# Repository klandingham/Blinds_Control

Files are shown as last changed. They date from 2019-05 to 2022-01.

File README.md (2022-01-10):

# Automatic Blinds Control with NodeMCU

A project to automatically open/close venetian blinds.

## Overall Description

## Circuit Operation

These are the elements outlined in John Gruber’s original design document. All Markdown applications support these elements.

### Heading

# H1
## H2
### H3

### Bold

**bold text**

### Italic

*italicized text*

### Blockquote

> blockquote

### Ordered List

1. First item
2. Second item
3. Third item

### Unordered List

- First item
- Second item
- Third item

### Code

`code`

### Horizontal Rule

---

### Link

[Markdown Guide](https://www.markdownguide.org)

### Image



## Extended Syntax

These elements extend the basic syntax by adding additional features. Not all Markdown applications support these elements.

### Table

| Syntax | Description |
| --- | --- |
| Header | Title |
| Paragraph | Text |

### Fenced Code Block

```
{
  "firstName": "John",
  "lastName": "Smith",
  "age": 25
}
```

### Footnote

Here's a sentence with a footnote. [^1]

[^1]: This is the footnote.

### Heading ID

### My Great Heading {#custom-id}

### Definition List

term
: definition

### Strikethrough

~~The world is flat.~~

### Task List

- [x] Write the press release
- [ ] Update the website
- [ ] Contact the media

### Emoji

That is so funny! :joy:

(See also [Copying and Pasting Emoji](https://www.markdownguide.org/extended-syntax/#copying-and-pasting-emoji))

### Highlight

I need to highlight these ==very important words==.

### Subscript

H~2~O

### Superscript

X^2^

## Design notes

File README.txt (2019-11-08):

______________________________________________________________________________
GIT REPOS
All projects now on github.

The old (obsolete) git workspaces are under:

    ~/Projects.repos.on.mycloud   DO NOT USE THESE, SAVED JIC

The new (active) git workspaces are under:

    ~/Projects.repos.on.github
   
______________________________________________________________________________
BOARDS

Remember when switching code via CodeSelect.h you must also edit
platformio.ini and define the target board. See for example:
     https://docs.platformio.org/en/latest/boards/espressif8266/nodemcuv2.html

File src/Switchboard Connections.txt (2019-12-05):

Switchboard Connections

 GND - T10
+12V - A11
  D1 - V13 (CAL LED)
+3V3 - U03
  D8 - C08 (CLOSE button)
  D6 - K08 (OPEN button)
  D0 - S08 (CAL button)

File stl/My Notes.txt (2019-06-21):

NOTE: UPDATE THIS README AS PROGRESS IS MADE!
NOTE: UPDATE THIS README AS PROGRESS IS MADE!
NOTE: UPDATE THIS README AS PROGRESS IS MADE!

Identifying parts:

	blind rod sleeve - the stem plate with the hexagonal hole which slides onto the blind rod.
	motor drive hub  - the solid cylinder that attaches to the stepper motor shaft
	spring cup       - the large hollow cylinder that houses the spring and the other parts.

Assembly:

	Slip the blind rod sleeve into the spring cup so that its stem protrudes from the hole in closed end of the sleeve.  Insert spring.  Attach the motor drive hub to the stepper motor using a hex set screw. Push the mounted motor hub into the spring cup.  Insert a cotter pin through one of the holes in the spring cup and then through the top hole (farthest from the motor).  Choose one of the holes in the spring cup to obtain the desired friction.

Parts still needed:

	1. Cottor pins (or something equivalent)
	2. Hex set screws
	3. Compression springs (may need to wind these myself)

Mod Notes:

1.	The hex opening in the original blind rod sleeve wasn't large enough for my blind rods.  I modded the design to fit using a larger hexagon for the hole - use "Blind Drive Hub Mod - 7.9.stl" - this fits snugly but will still slide on the rod.

2.	Because the outside diameter of the haft of the modded blind rod sleeve is larger than the original, the hole in the end of the spring cup must be made larger so the shaft will fit through it.  Have not done this mod yet.

3.	The outside circumferences of both the blind rod sleeve and the motor drive hub are binding inside the spring cup, probably due to 3D printing inaccuracies.  Both of these diameters need to be slightly reduced, so that both parts will spin freely inside the spring cup.  I can probably accomplish this by using a very thin cylinder shape to take away a bit of the circumference.  This mod has not been done yet.

4.	Because my stepper motors have short drive shafts, I can't get the motor drive hub deep enough into the spring cup to engage the last few tension adjustment holes.  I need to figure out how to mod the hub so that it will go deeper into the spring cup.  I don't want to simply make the entire cylinder taller if I can help it, because this is a solid part and that will use that much more filament.

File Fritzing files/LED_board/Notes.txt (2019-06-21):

Measurements of LED pushbuttons at desired brightnesses.

Drop resistor calculations: Vsupply - Vled / Iled

        Voltage Drop    Forward Current     Drop Resistor (@ 12V)
Blue      0.1 V              0.1 mA             100K
Green     1.9 V              2.4 mA             4K3
Red       1.7 V              0.15 mA            68K

Blue LED to be controlled by D1, but inverted. See Fritzing schematic
in this folder. D1 is to be NORMALLY HIGH, flash by setting it LOW
periodically (invert current logic).

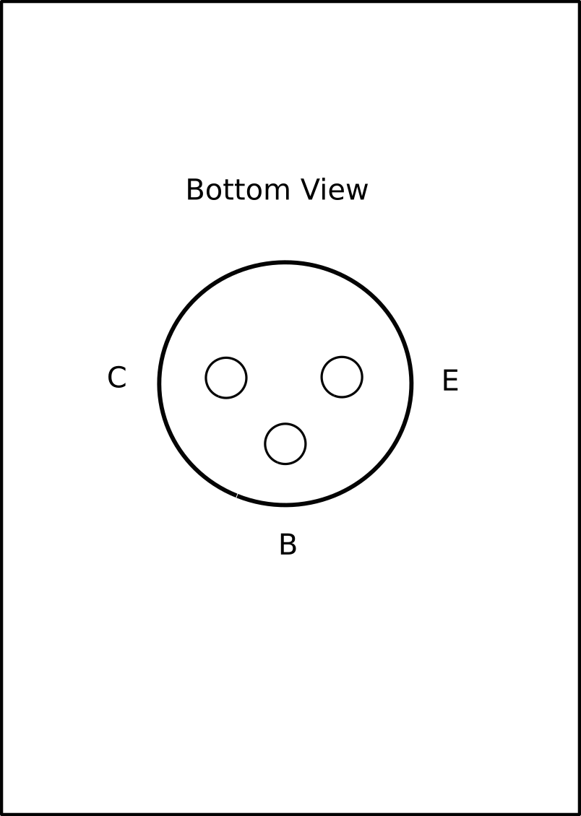
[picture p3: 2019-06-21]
Diagrams/Transistor_Pinout.png

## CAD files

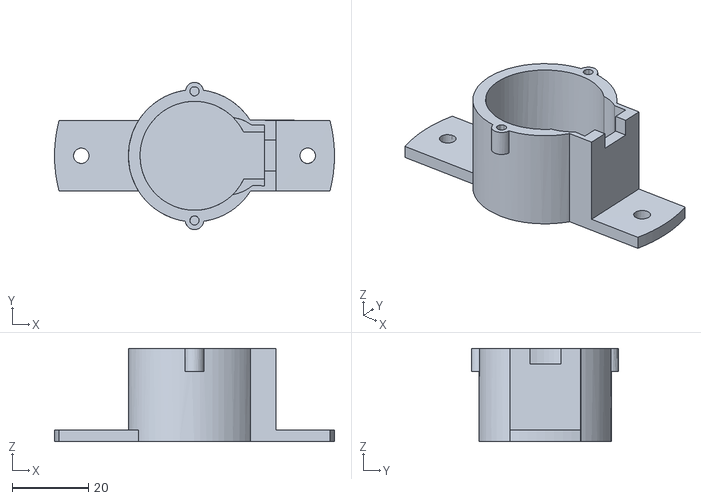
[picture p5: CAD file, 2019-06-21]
Example_Projects/28BYJ Window Mount.stl
73.4 x 38.6 x 24.5

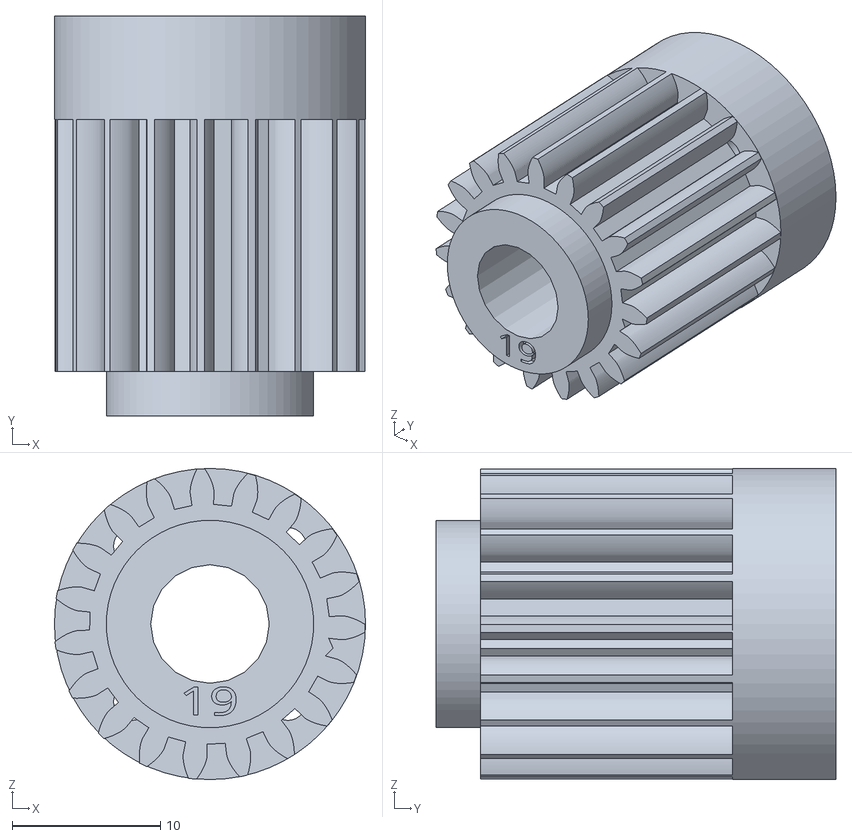
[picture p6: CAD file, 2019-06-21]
Example_Projects/Automated_window_blinds/files/Geared_Servo_Blinds-19Tooth.stl
21.0 x 27.0 x 21.0

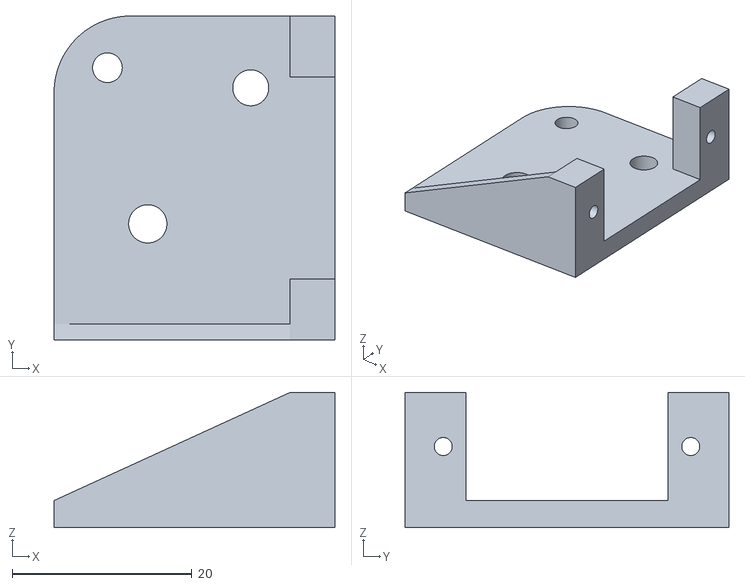
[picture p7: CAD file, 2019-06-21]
Example_Projects/Blinds_Automation_-_using_LinkIt_ONE/servo_mount_v3.stl
31.2 x 36.0 x 15.0

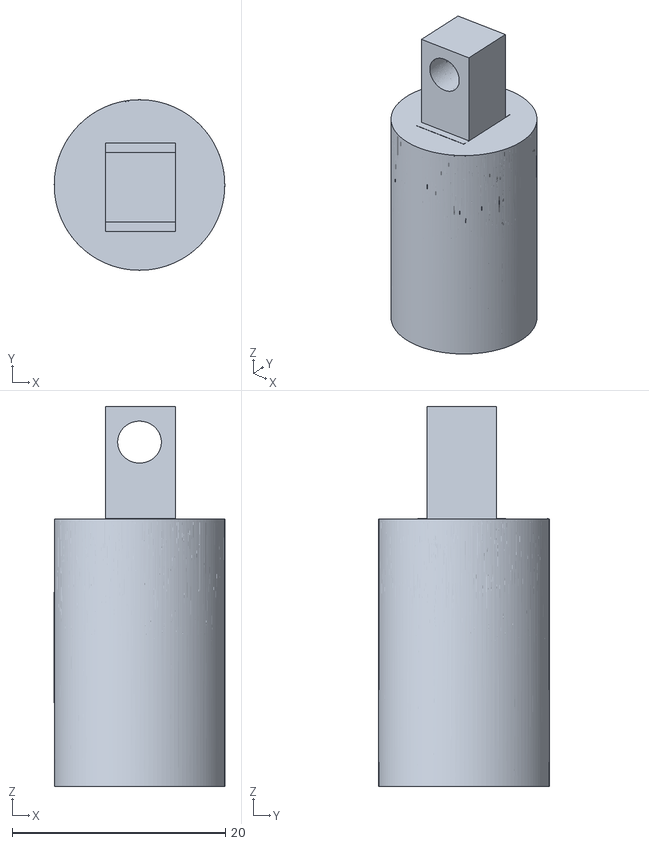
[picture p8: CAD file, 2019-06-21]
Example_Projects/Blinds_Stepper_Motor_Controller/files/rod-controller.stl
16.0 x 16.0 x 35.7

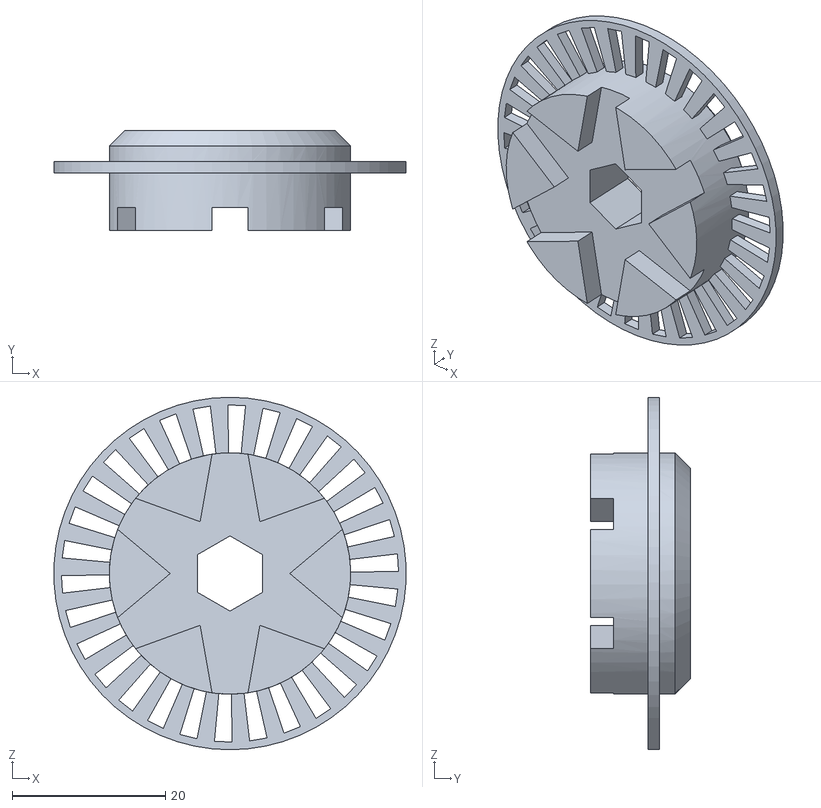
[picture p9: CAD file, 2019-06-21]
Example_Projects/BlindZer-master/3D STL Files/ServolClampWithEncoder.STL
45.9 x 13.0 x 46.0

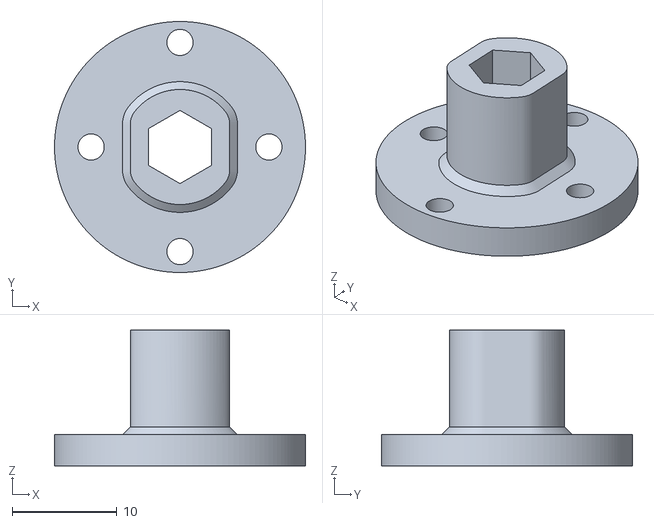
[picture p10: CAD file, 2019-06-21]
Example_Projects/Servo_Adapter_for_Automated_Blinds/files/adapter.stl
24.0 x 24.0 x 13.0

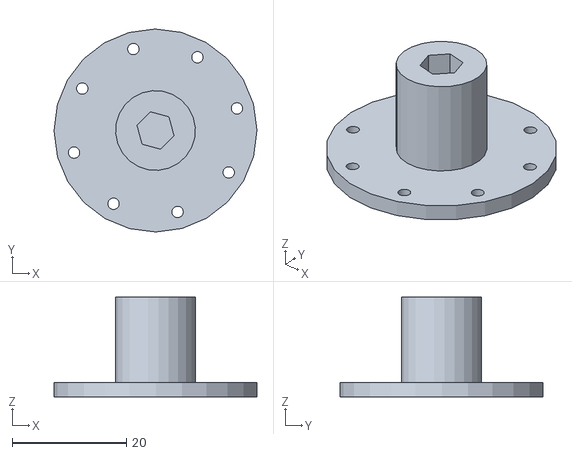
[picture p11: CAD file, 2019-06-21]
Example_Projects/Servo_adapter_for_blinds/files/Blind_adapter.stl
35.6 x 35.6 x 17.5

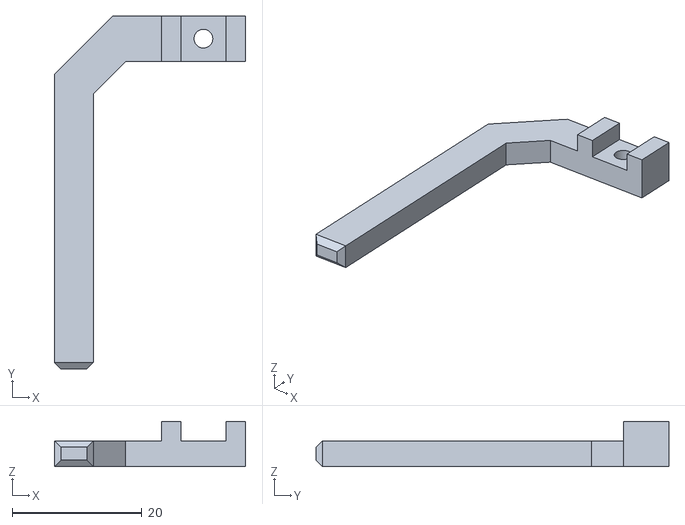
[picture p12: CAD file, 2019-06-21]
Example_Projects/WiFi_Window-Blinds_Roller/files/InterrupterMount.STL
29.5 x 54.5 x 7.00

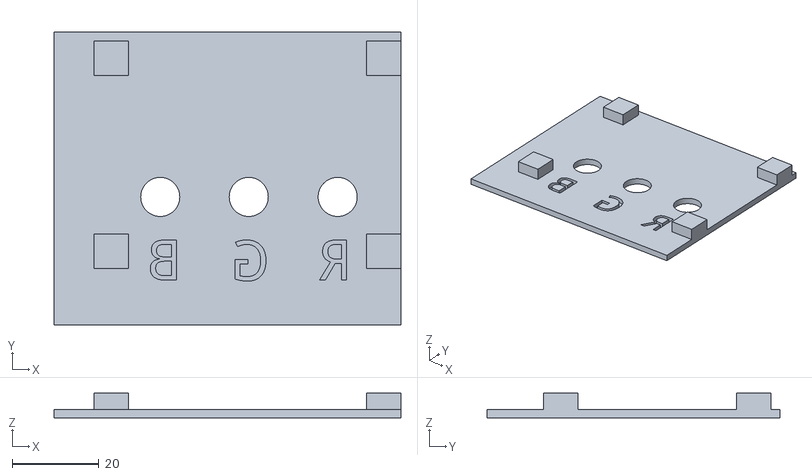
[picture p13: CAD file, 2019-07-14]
stl/box_cover/button_board_size_test_3.stl
80.0 x 67.5 x 5.75

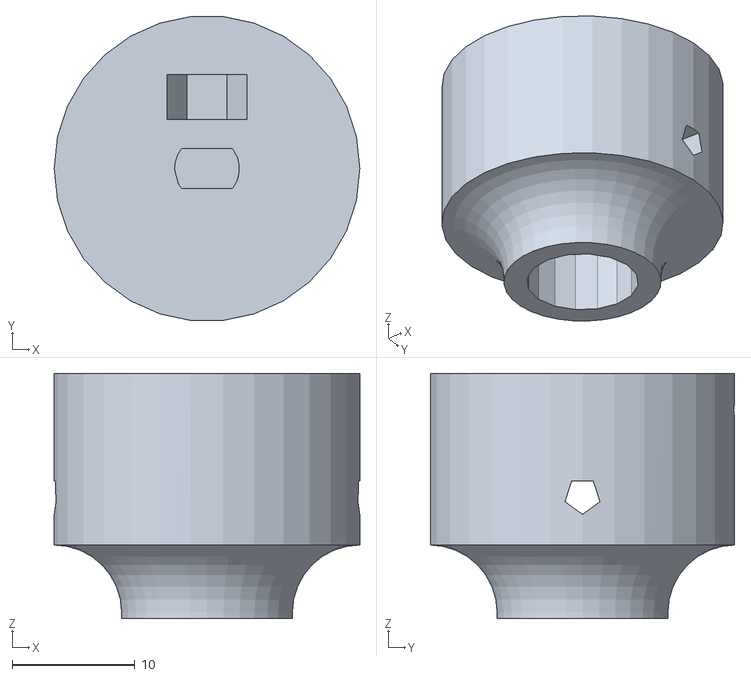
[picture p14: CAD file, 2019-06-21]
stl/Original Design/Blind Clutch Motor Hub Original.stl
24.9 x 24.8 x 20.0

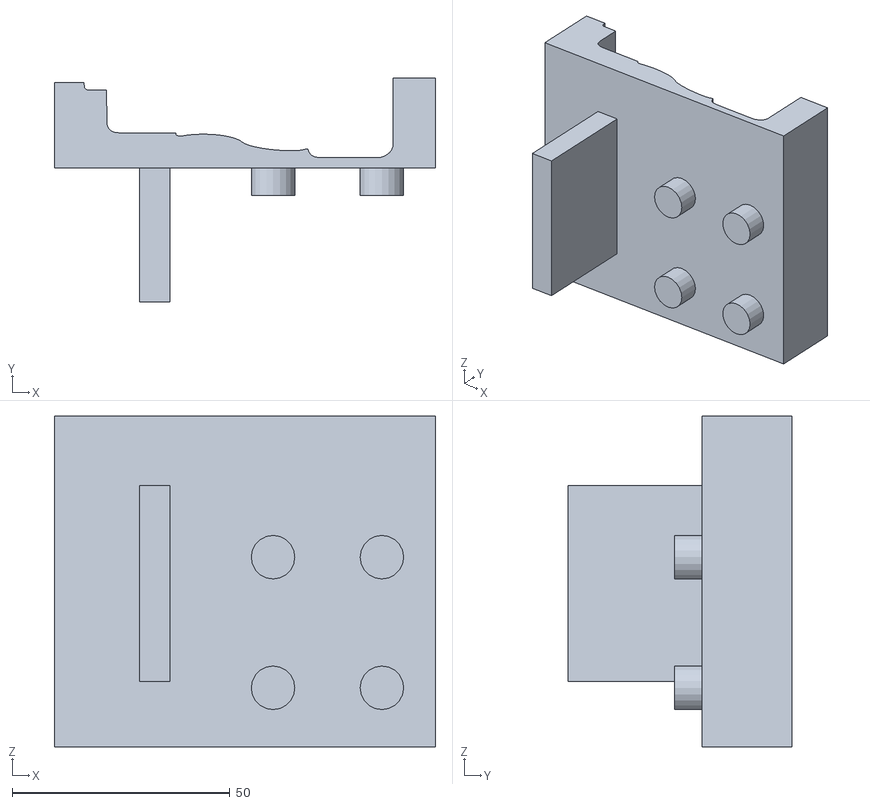
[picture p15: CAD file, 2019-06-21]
stl/Servo Mount/Window Trim Mount Base v2-vert.stl
87.5 x 51.4 x 76.0

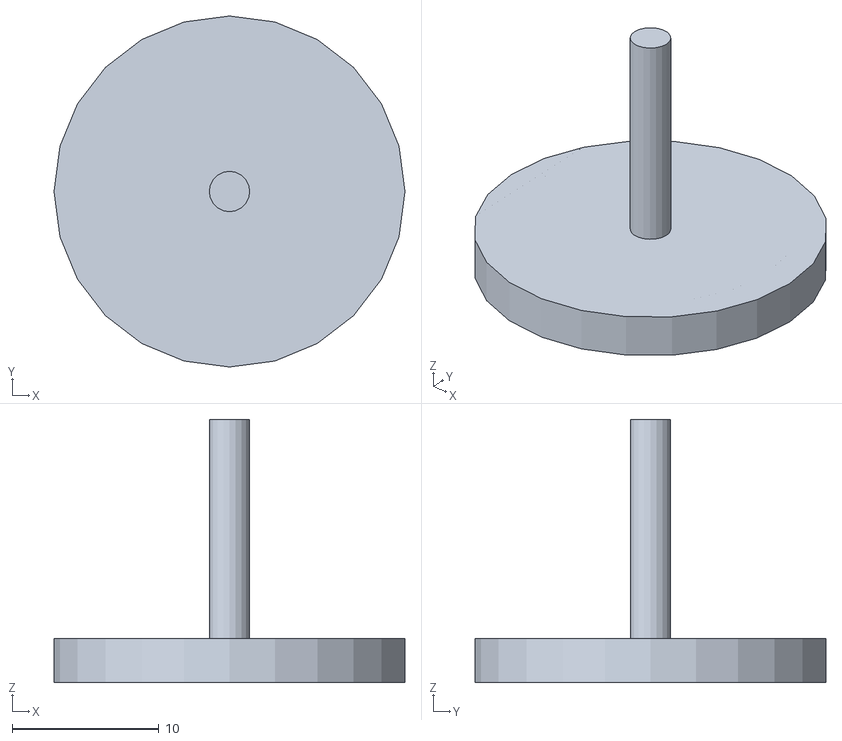
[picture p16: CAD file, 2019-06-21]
stl/Spring Cup I.D. Test.stl
23.9 x 23.9 x 17.9

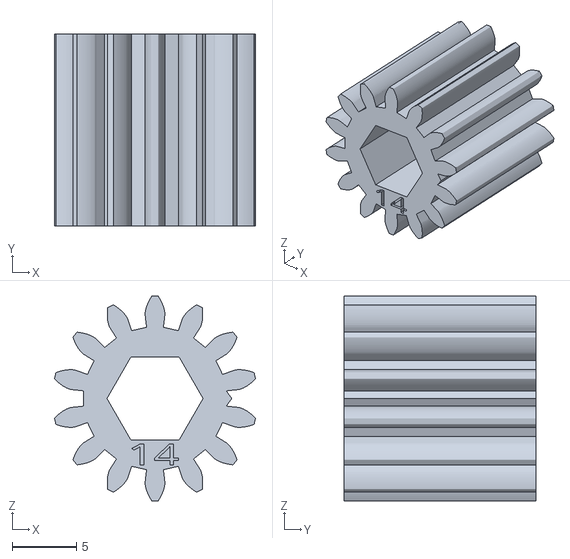
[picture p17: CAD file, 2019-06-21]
Example_Projects/Automated_window_blinds/files/Geared_Servo_Blinds-14Tooth.stl
15.7 x 15.0 x 16.0

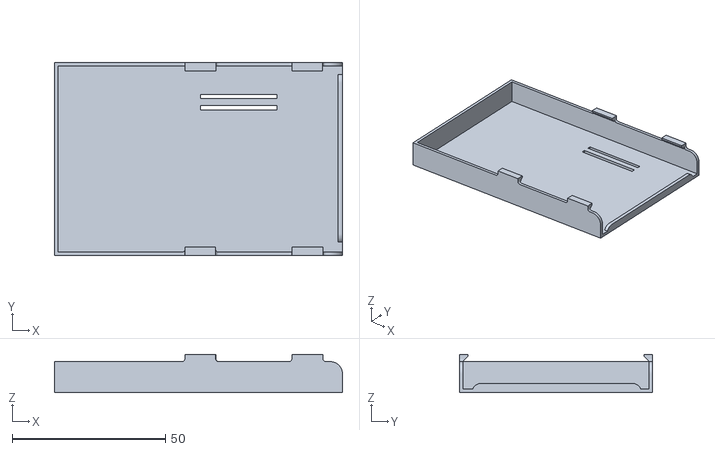
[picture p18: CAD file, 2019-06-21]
Example_Projects/Blinds_Automation_-_using_LinkIt_ONE/LinKItOne_TopV2.stl
94.0 x 63.1 x 12.5

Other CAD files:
Example_Projects/Blinds_Stepper_Motor_Controller/files/motor-container.stl
Example_Projects/BlindsRodAdapter.STL
Example_Projects/WiFi_Window-Blinds_Roller/files/BlindsRodAdapter.STL
Example_Projects/Automated_window_blinds/files/Centered_Geared_Servo_Blinds.stl
Example_Projects/Automated_window_blinds/files/Offset_Geared_Servo_Blinds.stl.stl
Example_Projects/BlindZer-master/3D STL Files/Assemly_PREVIEW.STL
Example_Projects/BlindZer-master/3D STL Files/BlindsRodAdapter.STL
Example_Projects/BlindZer-master/3D STL Files/ServoMount.STL
Example_Projects/Blinds_Automation_-_using_LinkIt_ONE/LinkItBaseV2_withScrews.stl
Example_Projects/Blinds_Automation_-_using_LinkIt_ONE/servo_horn_v2.stl
Example_Projects/WiFi_Window-Blinds_Roller/files/Assemly_PREVIEW.STL
Example_Projects/WiFi_Window-Blinds_Roller/files/BatteryBox-4.STL
Example_Projects/WiFi_Window-Blinds_Roller/files/ServoMount.STL
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

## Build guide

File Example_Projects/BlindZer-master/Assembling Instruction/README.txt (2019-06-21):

How to Assemble the Assembly?
- Follow pic 1 ~ 12

What else do I need to follow?
- Step 1~2: There is no predrilled hole for the screw, please force the screw into the Encoder whell
- Step 3~4: Screw size is M3, no screw nut is required to hold the interrupter securily
- Step 5~6: 
- Step 7~8: The feet of Optical Interrupter Assembly might require some trimming in order to fit into Servo Mount (Error introduced by FDM printer)
- Step 9~10: Please note the gap between blinds rod and the adapter, this is recommended for easier installation and operation

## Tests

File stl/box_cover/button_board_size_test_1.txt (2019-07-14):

12:58 PM 7/14/2019

This is an interim sizing template for the entire inset
that will go into the inside top of the cover.

I am using it to visually determine what the size and
placement will be for the corner mounting posts for the
board.

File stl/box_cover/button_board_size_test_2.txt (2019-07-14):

2:54 PM 7/14/2019

Follow-on sizing plate for button board.

Contains test locations for corner mounting pads.

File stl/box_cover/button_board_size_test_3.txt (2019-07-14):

4:21 PM 7/14/2019

Pad positions adjusted.

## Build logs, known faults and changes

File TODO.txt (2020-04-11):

TODO.txt

Sun Mar 15 13:53:51 EDT 2020
============================
[x] Create duplicate "working" KiCAD files to be used while
wiring the main board: as each connection is completed,
remove it from the diagram.

Tue Jan 21 23:34:00 EDT 2020
============================
[x] Pull-up resistors need to be added to board.

[x] The sockets for the shift register ICs are the wrong size!
They are 14-pin sockets. The ICs are 16-pin. Current sockets
need to be removed and replaced with 16-pin types. After
replacement, the PCB pin IDs will need to be updated in the
schematic.

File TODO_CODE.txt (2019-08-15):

Go through the code - whereever possble, replace int and unsigned types with
uint8_t (unsigned 8-bit integer, min=0, max=255). These are smaller than int
and unsigned and will save memory space.

Right now the code uses polling to detect button presses. A better way is to
use hardware interrupts (see Youtube for tutorials). But, AFAIK, the standard
Arduino UNO only supports 2 hardware interrupts, and I have three buttons. I
suppose there's a chance that the WAVGAT clone might support more interrupts
...I'll need to try to research that.

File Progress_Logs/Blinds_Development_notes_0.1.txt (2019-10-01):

==============================================================================
Development Notes for Automatic Window Blinds

Version 0.1 - Servo motor solution - abandoned due to test servo motor
shorting out after only minimal testing. Decided these servos are not reliable
enough. Going back to a stepper motor approach.

==============================================================================

==============================================================================
STATUS: Just finished speed selection test sketch. Varies servo value across
a fixed array of values via pushbutton presses. Noted that pb needs real
debouncing! (see Debounce example).
==============================================================================
==============================================================================
NEXT TASK:

Modify the speed selection sketch to use one "medium" speed value. Change the
button logic to switch a transistor - see if I can turn the servo on/off via
the button.
Need to find a suitable transistor (test manually with the speed selection
sketch running on high speed).

==============================================================================

Decided to use servo motors instead of steppers. Will use clutch assemblies
already printed, driven directly by motors. Will need to design and print
a new base part that can attach to one of the horns supplied with the servo.

Current operation design:
	3 pushbuttons:
		1 - servo selection
		2 - close button
		3 - open button

Open/close buttons will operate on timeout:
	close button pushed:
		wait 1 second
		if close button still pushed
			move in close direction until close button released
		else
			send measured close
	open button pushed:
		wait 1 second
		if open button still pushed
			zero out open interval for all enabled servos
			move in open direction until open button released
			on release save measured interval for enabled servos
		else
			send measured open

DONE: ServoDutyCycle.ino varies duty cycle (DC) to servo using potentiometer.
Need to add serial output to show DC values as I adjust the pot. Then pick
one or two DC values each for forward/reverse and save these for the final
sketch. 8/13 update: after experimentation with this sketch, found that only
a few values were usable for the blinds project. Here are the speeds and
values (as args to analogWrite() in the sketch) I found:

	fast CCW = 67 to 68
	med  CCW = 69 to 70
	slow CCW = 71 to 72
	stop     = 73 to 76 (will probably disable trasistors instead)
	slow  CW = 77 to 78
	med   CW = 79 to 80
	fast  CW = 81 to 82

TODO: Write a "speed select" test to see if I can cycle through each
of these fixed speed values by repeatedly pressing a button.

Servo Switching Transistors:
Measured SM-S4306 servo under load: min 0.5 A xsistors should handle the
current.

DONE: Want to enable/disable each servo by switching power to each using a
control transistor. Need to measure current draw (under load) of servo in
both directions to determine current requirements that will be required
of these transistors.

TODO: Need to come up with code that will allow enabling of servos using
repetitive presses of a single selection button. Will need to step through
each combination, something like:

	0 0 0 (all disabled)
	0 0 1 (1 enabled)
	0 1 0 (2 enabled)
	1 0 0 (2 enabled)
	0 1 1 (1,2 enabled)
	1 1 0 (2,3 enabled)
	1 0 1 (1,3 enabled)
	1 1 1 (all enabled)

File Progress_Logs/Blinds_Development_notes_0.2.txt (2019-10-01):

==============================================================================
Development Notes for Automatic Window Blinds

Version 0.2 - Based on Version 0.1, but going back to a stepper motor
approach.

==============================================================================

==============================================================================
STATUS: Have reconstructed basic circuit (with 74HC595 and one servo.) Using
Shift_Register_RAW example circuit to drive it right now. Will base final
sketch on this example. Needs to be modified to move motor faster. Also need
to modify the sequence patterns to get stronger torque.
==============================================================================
==============================================================================
NEXT TASK:

The example code I am currently using uses explicit boolean patterns to drive
the motor. This works, but it's clunky, error-prone and difficult to modify.
I'm almost positive that in the latest code I was working on before the disk
crash, I was using a technique to translate an integer value to a bit pattern
then sending the result to the shift register. In fact, I remember that I was
driving one stepper with the 4 low order bits and a second one with the high
order bits. I need to find out how I did that (likely a built-in Arduino
function) and resurrect it.

I remember finding a very good YT video (by a guy at Microsoft) describing
how stepper motors work, and in particular showing the different driving
patterns that can be used and their characteristics. I need to find that
video again. Perhaps I saved it as a favorite in a browser.

Create working sketch based on example mentioned above. Modify rotation speed
and cycle patterns.
==============================================================================

Since I'm back to using steppers, I will need to save the total number of
steps required for open/close. (NOTE: will I need to store a separate count
for each motor? Shouldn't have to, since all the motors are identical, but
time will tell.)

Current operation design:
	3 pushbuttons:
		1 - servo selection
		2 - close button
		3 - open button

Open/close buttons will operate on timeout:
	close button pushed:
		wait 1 second
		if close button still pushed
			move in close direction until close button released (calibrate closed)
		else
			move in close direction for saved number of steps
	open button pushed:
		wait 1 second
		if open button still pushed
			set open-step-counter to 0
			move in open direction until open button released, counting steps
			on release save step counter value
		else
			move in open direction for saved number of steps

==============================================================================
TODO:
Need to measure current drawn by stepper under load. Will need the enabling
transistors to handle at least this much current.

TODO: Need to come up with code that will allow enabling of servos using
repetitive presses of a single selection button. Will need to step through
each combination, something like:

	0 0 0 (all disabled)
	0 0 1 (1 enabled)
	0 1 0 (2 enabled)
	1 0 0 (2 enabled)
	0 1 1 (1,2 enabled)
	1 1 0 (2,3 enabled)
	1 0 1 (1,3 enabled)
	1 1 1 (all enabled)

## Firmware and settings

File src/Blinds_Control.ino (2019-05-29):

/*

  Blinds_Control

        New issue: with the 12V power supply I chose, when the circuit is first
        switched on, it apparently is drawing a large enough initial surge of
        current to trip the overcurrent protection inside the wall transformer.
        The result is that the power begins to pulse on and off (about once
        every two seconds) and the circuit doesn't function. I've noticed that
        when first switched on, all the stepper driver board LED's flash which
        suggests that they are all being switched on at power up. I also noticed
        that once the PS goes into its power-trip cycle, if I disconnect Vcc
        from the first 74595, the cycling stops...I can they reconnect the shift
        register, and the circuit behaves normally. So it seems I need some sort
        of delay to enable the shift register outputs once the circuitry is
        stable after power up.

        Right now I have the output enable (OE) lines (active low) pins hard-wired
        to ground (i.e. the register outputs are instantly enabled). I'm going
        to try using one of the NodeMCU pins to enable these pins on startup,
        perhaps after one second. Hopefully this will get rid of this initial
        surge issue. THIS DIDN'T WORK...I'll just add a power switch for each
        stepper driver board - was going to do that anyway.

  v0.9: Finally got to test this on a real window blind! Two issues surfaced:

        (1) I want to use 8-conductor Ethernet cable to get signals and power to
        each stepper module (cheap). As an initial test, I reconnected one of
        the modules using a 6 foot length of this cable. Unfortunately, the
        conductor gauge used in this cable, although adequate to carry network
        signals a considerable distance, falls short when asked to carry any
        appreciable amount of current. I found that while driving the stepper,
        the 5V supplied at the board had dropped to around 3.5V by at the
        stepper module (a considerable loss), and that is with only a 6 ft
        length. Cable to the farthest window will result in an even greater
        amount of voltage loss. At this reduced voltage, the stepper motor
        was VERY weak. To solve this, I am using a two-fold approach. First,
        I have replaced the 5V power supply with a 12V one (the maximum
        rated input voltage for the stepper modules). Second, when assembling
        the longer cables, since the cable I am using has 8 conductors and I
        am only using 6, I will double-up the cables on the 2 power pins (that
        is, crimp 2 conductors into each of the 2 power connectors).

        (2) This particular issue could be a show-stopper! Testing the current
        implementation with a real window blind, I quickly realized that the
        stepper motors are rotating far too slowly to be practical. The number
        of complete rotations necessary to open the blinds seems to be around
        4 to 5, but with my current implementation that could take several
        minutes of holding down a button - not usable. I am going to try to
        modify the timings in the sketch to try to get the steppers to rotate
        faster, BUT I realize that there is a limit to how fast they will rotate
        reliably. Hopefully upping the power supply voltage (see #1 above) will
        help. If I CANNOT get the steppers to rotate fast enough to be usable,
        I will have to go back to using servo motors - that will require not
        only changing the code but also creating new parts!

        UPDATE: Increasing the stepper power supply voltage from 5 to 12V seems
        to have solved the speed issue - I have been able to remove the loop
        delay and all 3 steppers seem able to keep up with the code.

  v0.8: Modified sequence output values to drive 3rd motor.
  
  v0.7: Decided on using toggle switches to select motors.
        Modified sequence output values to drive 2nd motor.

  v0.6: Woo-hoo! Button logic FINALLY working:
    To calibrate:
      1. Press and hold CLOSE button until blinds are closed.
      2. Press CALIBRATE button (LED will blink).
      3. Press and hold OPEN button until blinds are open. (LED stops)
    To use:
      Press either OPEN or CLOSE button to open/close blinds!

  NEXT: Need to figure out how to select motors. Presents a problem because
  I want to show which are selected with LED's, but I don't have enough open
  pins left on the NodeMCU. Thinking about using some sort of external logic
  chip to do the selection sequence, but it's not going to be binary...it will
  need to be something like:

        0 0 0  (I guess this would be "all motors off"...entire thing disabled)
        0 0 1
        0 1 0
        1 0 0
        0 1 1
        1 1 0
        1 1 1
  Also considering a simpler hardware solution: a small toggle switch for each
  motor.
        

  v0.5: Replacing excessively complex button logic with simpler approach:
  Add one more button "Calibrate"...press this to go into calibrate (CAL) mode
  (a CAL LED flashes), optional: press and hold CLOSE to move blinds to closed,
  press and hold OPEN until blinds at desired position, release OPEN button (I save
  duration), press CAL button to exit calibration mode. From this point onward, OPEN
  and CLOSE buttons use the measure duration. Addition: keep track of OPEN or CLOSED
  state. When not in CAL mode, if blinds are OPEN, ignore OPEN button, likewise for
  CLOSE button.

  v0.4: Added button processing logic - but getting bad interactions between the buttons.
  The button processing with long-press detection is just too complex. I've decided to
  use a different approach. See next version.

  v0.3: Decided that using interrupts to handle button presses is overkill.
  Restructured the code so that the main loop handles controls (buttons,
  etc.) processing, and refactoring the stepper driver code. Added function
  to process button states at top of main loop. Loop currently contains
  debugging code for this function.

  v0.2: Added pushbutton interrupt handler. Currently changes direction
  of stepper motor, just as a test.

  v0.1: Basic stepper drive logic. Still has code from base example
  that needs to be cleaned out.

  This sketch controls 28BYJ-48 stepper motors via a shift register to
  open/close window blinds.

*/

// 74HC595 control pins
const int latchPin = D2;  // pin 12 on the 75HC595
const int clockPin = D5;  // pin 11 on the 75HC595
const int dataPin  = D7;  // pin 14 on the 75HC595

// CALibrate related pins
const int calibrateLEDPin = D1;

// Motor drive modes
enum CommandState {
  OPEN,
  CLOSE,
  AUTO_OPEN,
  AUTO_CLOSE,
  STOP
};

CommandState command = STOP;

int autoTimeInterval; // this is the measured time to move from opened to closed and vice-versa
int autoStartTime;    // time at which a manual OPEN is started - used to measure required auto interval

const int closeButton = D8;
const int openButton  = D6;
const int calibrateButton = D0;

boolean calibrating = false;
int calibrateFlashTime;
boolean calibrateLEDOn = false;
int lastLoopTime = 0;

// Values for two-phase, full-step operation (AB->BC->CD->DA)
const int fullStepValueCount = 4;
int TF_stepperValues1[4]   = {  12,     6,    3,    9};
int TF_stepperValues2[4]   = { 192,    96,   48,  144};
int TF_stepperValues3[4]   = {3072,  1536,  768, 2304};
int TF_stepperValues12[4]  = { 204,   102,   51,  153};
int TF_stepperValues123[4] = {3276,  1638,  819, 2457};
int stepIndex;

boolean isOpening = true;

//////////////////////////////////////////////////////////////////////////////
// If in the middle of a motor sequence and command becomes stop, we could be
// leaving one set of coils in the motors energized indefinitely. This method
// turns all coils off to ensure that doesn't happen.
void DeenergizeMotors() {
  digitalWrite(latchPin, LOW);              // ready shift register for data
  shiftOut(dataPin, clockPin, MSBFIRST, 0); // set all coil bits to 0
  digitalWrite(latchPin, HIGH);             // latch shift register (sends bits to motor(s))
} // DeenergizeMotors()

//////////////////////////////////////////////////////////////////////////////
// Sends next bit pattern to motor(s). Moves value index according to specified direction.
void SendNextSequence(boolean opening) {
  Serial.print("SendNextSequence: stepIndex = ");
  Serial.println(stepIndex);
  // Note: using a global for sequence (step) index so I can start it at 0 in setup()
  static uint16_t serialValue;
  // moving this delay to the main loop!  delay(10);  // delay for stepper motor...may need adjustment in final version
  // Note: will need to replace next statement with computation: add to final value
  // for each enabled motor; right now just driving motor 1
  serialValue = TF_stepperValues123[stepIndex];  // get next value (bit pattern) to output
  digitalWrite(latchPin, LOW);  // ready shift register for data
  shiftOut(dataPin, clockPin, MSBFIRST, serialValue); // send value to shift register
  digitalWrite(latchPin, HIGH);  // latch shift register (sends bits to motor(s))
  if (opening) {
    stepIndex++;
    if (stepIndex >= fullStepValueCount) {
      stepIndex = 0;
    }
  }
  else {
    stepIndex--;
    if (stepIndex < 0) {
      stepIndex = fullStepValueCount - 1;
    }
  }
} // SendNextSequence()

//////////////////////////////////////////////////////////////////////////////
void setup() {

  Serial.begin(115200);

  pinMode(closeButton, INPUT_PULLUP);
  pinMode(openButton, INPUT_PULLUP);
  pinMode(calibrateButton, INPUT);

  pinMode(dataPin, OUTPUT);
  pinMode(latchPin, OUTPUT);
  pinMode(clockPin, OUTPUT);
  pinMode(calibrateLEDPin, OUTPUT);

  command = STOP;
  calibrateFlashTime = 125; // mS
  digitalWrite(calibrateLEDPin, LOW);
  stepIndex = 0;
} // setup()

int autoOpTime;
int calibrationStartTime;
boolean autoOpInProgress = false;
boolean calibrationInProgress = false;

int calibrateButtonState = 0;
int lastCalibrateButtonState = 0;
int closeButtonState = 0;
int lastCloseButtonState = 0;
int openButtonState = 0;
int lastOpenButtonState = 0;

//////////////////////////////////////////////////////////////////////////////
void loop() {
  static int autoStartTime; // the time at which an auto-open/close op begins

  //
  //
  // Check state of calibrate button
  //
  calibrateButtonState = digitalRead(calibrateButton);
  if (calibrateButtonState != lastCalibrateButtonState) {
    if (calibrateButtonState == HIGH) {
      calibrating = !calibrating;
    }
  }
  lastCalibrateButtonState = calibrateButtonState;
  //
  //
  // Flash calibration LED if in calibrate mode
  //
  if (calibrating) {
    if (lastLoopTime == 0) {
      lastLoopTime = millis();
    }
    else if ((millis() - lastLoopTime) > calibrateFlashTime) {
      if (!(calibrateLEDOn)) {
        calibrateLEDOn = true;
        digitalWrite(calibrateLEDPin, HIGH);
      }
      else {
        calibrateLEDOn = false;
        digitalWrite(calibrateLEDPin, LOW);
      }
      lastLoopTime = 0;
    }
  }
  else {
    calibrateLEDOn = false;
    digitalWrite(calibrateLEDPin, LOW);
  }
  //
  //
  // Read CLOSE button. If in calibrate mode, keep command at
  // CLOSE as long as button is pressed (HIGH), set command to
  // STOP on release. If in normal mode, if command is not
  // AUTO_CLOSE, set it to that, ignore release.
  //
  closeButtonState = digitalRead(closeButton);
  if (closeButtonState != lastCloseButtonState) {
    if (calibrating) {
      if (closeButtonState == HIGH) {
        command = CLOSE;
      }
      else {
        command = STOP;
      }
    }
    else { // else not calibrating
      if ((closeButtonState == HIGH) && (command != AUTO_CLOSE)) {
        command = AUTO_CLOSE;
      }
    }
  }
  lastCloseButtonState = closeButtonState;


  // TODO: handle OPEN button (must do timing)

/*
  // while calibrating, don't need to know if button changed,
  // just need to know if it's pressed or not
  if calibrating
    if button HIGH (pressed)
      if already measuring
        open -> command
      else
        true -> measuring
        set start time
        open -> command
      fi
    else // button is LOW
      if already measuring // always true?
        duration = now - start time
        stop -> command
        false -> measuring
        false -> calibrating
      fi
      // ? need case for not already measuring?
    end else button is LOW
  end if calibrating
  else // not calibrating
    false -> measuring
    0 -> start time
    handle OPEN button as in CLOSE case
*/

  //
  //
  // Read OPEN button. If in calibrate mode and button pressed,
  // start calibration if not already started.
  //
  openButtonState = digitalRead(openButton);
  if (calibrating) {
    if (openButtonState == HIGH) { // if button is pressed
      if (!calibrationInProgress) { // if not measuring yet
        calibrationInProgress = true;
        calibrationStartTime = millis();
      } // end if not measuring yet
      command = OPEN;
    } // if button is pressed
    else { // else button is not pressed
      if (calibrationInProgress) { // if currently measuring
        autoOpTime = millis() - calibrationStartTime;
        command = STOP;
        calibrationInProgress = false;
        calibrating = false;
      } // end if currently measuring
    } // end else button is not pressed
  } // end if calibrating
  else { // else if not calibrating
    if (openButtonState != lastOpenButtonState) { // if button just changed state
      if ((openButtonState == HIGH) && (command != AUTO_CLOSE)) { // if button pressed and we're not already in AUTO_OPEN mode
        command = AUTO_OPEN;
      }
    } // end if button just changed state
  } // end else not calibrating
  lastOpenButtonState = openButtonState;





  //
  //
  // Command processing. Note we only measure time during an OPEN
  // operation.
  //
  if (command == STOP) {
    DeenergizeMotors();
  }
  else if (command == AUTO_CLOSE) {
    if (!(autoOpInProgress)) { // if this is new auto command
      autoOpInProgress = true;
      autoStartTime = millis();
      SendNextSequence(false);
    } // if this is new auto command
    else { // else an auto open/close is already in progress
      if ((millis() - autoStartTime) >= autoOpTime) { // if auto time satisfied
        autoOpInProgress = false;
        autoStartTime = 0;
        command = STOP;
      }
      else {
        SendNextSequence(false);
      }
    }
  } // if AUTO_CLOSE
  else if (command == AUTO_OPEN) {
    if (!(autoOpInProgress)) { // if this is new auto command
      autoOpInProgress = true;
      autoStartTime = millis();
      SendNextSequence(true);
    } // if this is new auto command
    else { // else an auto open/close is already in progress
      if ((millis() - autoStartTime) >= autoOpTime) { // if auto time satisfied
        autoOpInProgress = false;
        autoStartTime = 0;
        command = STOP;
      }
      else {
        //      Serial.println("Continuing auto op");
        SendNextSequence(true);
      }
    }
  } // if AUTO_OPEN
  else if (command == OPEN) {
    SendNextSequence(true);
  }
  else if (command == CLOSE) {
    SendNextSequence(false);
  }
  // Note: had a delay in here because the steppers were skipping. Increased the
  // stepper power voltage from 5 to 12V. No delay is necessary now (the stepper
  // motors can keep up with the code.)
} // loop()

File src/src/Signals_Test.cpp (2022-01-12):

/*

  Signals_Test (NodeMCU version)

  This is a modified version of Blinds_Control_NodeMCU.cpp - modified to
  continually produce stepper rotation signals. Intended to be used for
  troubleshooting.

  Controls 28BYJ-48 stepper motors via shift registers to
  open/close window blinds. See history.txt

  NOTE: For NodeMCU (and other boards) pin mapping, see:

    https://github.com/esp8266/Arduino/blob/master/doc/boards.rst#pin-mapping

*/
#include "CodeSelect.h"
#ifdef SIGNALS_TEST

// #define TRACE

#include <Arduino.h>

// pin assignments
// NodeMCU
//const int latchPin = D2;  // to pin 12 on the 75HC595
//const int clockPin = D5;  // to pin 11 on the 75HC595
//const int dataPin  = D7;  // to pin 14 on the 75HC595
// WAVGAT
const int latchPin = 4;   // to pin 12 on the 75HC595
const int clockPin = 2;   // to pin 11 on the 75HC595
const int dataPin  = 3;   // to pin 14 on the 75HC595
const int resetPin = 5;   // for testing only

const int fullStepValueCount = 4;
const int stepDelay = 250; // milliseconds
// values for two-phase, full-step operation (AB->BC->CD->DA)
// examples:
//
// single motor:
//  1100 (12)
//  0110 (6)
//  0011 (3)
//  1001 (9)
// two motors:
//  11001100 (204)
//  01100110 (102)
//  00110011 (51)
//  10011001 (153)
int TF_stepperValues1[4]   = {  12,     6,    3,    9};
int TF_stepperValues2[4]   = { 192,    96,   48,  144};
int TF_stepperValues3[4]   = {3072,  1536,  768, 2304};
int TF_stepperValues12[4]  = { 204,   102,   51,  153};
int TF_stepperValues123[4] = {3276,  1638,  819, 2457};
int stepIndex;

//////////////////////////////////////////////////////////////////////////////
// Sends next bit pattern to motor(s). Moves value index according to specified direction.
void SendNextSequence(boolean opening) {
    // Note: using a global for sequence (step) index so I can start it at 0 in setup()
    static uint16_t serialValue;
    // moving this delay to the main loop!  delay(10);  // delay for stepper motor...may need adjustment in final version
    // Note: will need to replace next statement with computation: add to final value
    // for each enabled motor; right now just driving motor 1
    serialValue = TF_stepperValues123[stepIndex];  // get next value (bit pattern) to output
    digitalWrite(latchPin, LOW);  // ready shift register for data
    delay(5);
    shiftOut(dataPin, clockPin, MSBFIRST, serialValue); // send value to shift register
    digitalWrite(latchPin, HIGH);  // latch shift register (sends bits to motor(s))
    delay(5);
    if (opening) {
        stepIndex++;
        if (stepIndex >= fullStepValueCount) {
        	stepIndex = 0;
        }
    }
    else {
        stepIndex--;
        if (stepIndex < 0) {
        	stepIndex = fullStepValueCount - 1;
        }
    }
} // SendNextSequence()

// Send 10101010 to shift register, latch, delay, then clear
void SendBitPattern() {
	int clockDelay = 10; // milliseconds
	uint8_t bit = 0;
	uint8_t bitToggle = 0;
	digitalWrite(latchPin, LOW);
	digitalWrite(clockPin, LOW);
	for (int i = 0; i < 8; i++) {
		digitalWrite(resetPin, HIGH);
		if (++bitToggle > 2) {
			bit = !bit;
			bitToggle = 0;
		}
		delay(clockDelay);
		digitalWrite(dataPin, bit);
		delay(clockDelay);
		digitalWrite(clockPin, HIGH);
		delay(clockDelay);
		digitalWrite(clockPin, LOW);
		digitalWrite(latchPin, HIGH);
		delay(clockDelay * 8);
		digitalWrite(resetPin, LOW);
		digitalWrite(latchPin, LOW);
	}
}
//////////////////////////////////////////////////////////////////////////////
void setup() {

    Serial.begin(9600);

    while (!Serial)  // Wait for the serial connection to be established.
      delay(50);

    pinMode(dataPin, OUTPUT);
    pinMode(latchPin, OUTPUT);
    pinMode(clockPin, OUTPUT);

    stepIndex = 0;
} // setup()

//////////////////////////////////////////////////////////////////////////////
void loop() {
    // Simply send the next sequence in the OPEN direction
    SendNextSequence(true);
    // delay(1);
    // Note: If stepper driver lights come on, but motor does not turn, try adding a delay here.
    // first, test outputs to 74595
	// SendBitPattern();
} // loop()

#endif

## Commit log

2019-05-29 Blinds Control Arduino Code - initial commit
2019-06-21 Added STL, Fritzing and reference files.
    [28BYJ Window Mount.stl, Assemly_PREVIEW.STL, Automatic Blinds v0.1.fzz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]
2019-06-21 Moved example projects into new directory.
    [28BYJ Window Mount.stl, Assemly_PREVIEW.STL, BatteryBox-4.STL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]
2019-06-21 Moved Fritzing and STL files.
    [Automatic Blinds v0.1.fzz, Automatic Blinds v0.2.fzz, Automatic Blinds.fzz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]
2019-06-21 Added circuit and notes for blue button LED drive.
    [Blue Button LED Switching Circuit.fzz]
2019-07-07 Added subdirectory for box STL files.
    Added box cover.
    Added test for button board inset in top of box.
    [ButtonBoardInsetTest.stl, box.stl]
2019-07-07 Added button diameter test STL.
    [button_hole_diam_test.stl]
2019-07-08 Added STL test file for button spacing.
    [button_spacing_test.stl]
2019-07-09 Adjusted button hole spacing on button_spacing_test.stl
    Now fits the buttons.
    [button_spacing_test.stl]
2019-07-14 Added test STL for button board sizing.
    [button_board_size_test_1.stl, button_board_size_test_2.stl]
2019-07-14 Added update to button board sizing test (pad positions adjusted).
    Deleted unused file.
    [ButtonBoardInsetTest.stl, button_board_size_test_3.stl]
2019-07-14 Added .txt extension to text files for easier opening in Windows.
    Updated STATUS.txt with latest status and current plans.
2019-08-05 Added pinout diagram for shift register.
    Updated notes in Fritzing breadboard diagram.
    [Node MCU Control Circuit WORKING COPY.fzz]
2019-08-06 Finished schematic in NodeMCU sketch. Also "saved as" Arduino version.
    Next to do: re-edit the Arduino version and replace the NodeMCU with an
    Arduino board. Then (possibly) edit it further to match the WAVGAT UNO
    board (may not be necessary.)
    [Node MCU Control Circuit WORKING COPY.fzz, WAVGAT (Arduino) Control Circuit WORKING COPY.fzz]
2019-08-06 Added sample circuit for driving shift register with Arduino.
2019-08-07 Corrected board input voltage: changed from 12 to 5 volts.
    Note: this means that for Arduino/WAVGAT, the buck converter will not be necessary
    [Node MCU Control Circuit WORKING COPY.fzz, WAVGAT (Arduino) Control Circuit WORKING COPY.fzz]
2019-08-14 Modified wiring diagram for WAVGAT version of circuit. Added property files for platformio and VSCode. Changed code file extension to .cpp Moved change history out of code file to separate text file.
    [WAVGAT (Arduino) Control Circuit WORKING COPY.fzz]
2019-08-16 Continued work on WAVGAT code. Added board selection header to switch code files on and off. Added TestCode.cpp for anything I need to test.
2019-08-16 WAVGAT code now working (nominally).
    There is some sort of logic error - see STATUS.txt
    [Blinds_Control_WAVGAT.cpp]
2019-08-18 Fixed bug due to millis() values rolling over.
    [Blinds_Control_WAVGAT.cpp]
2019-08-19 Now working with IR remote.
    Added pinout diagram for IR sensor.
    Removed history.txt - wasn't maintaining it.
    Renamed BoardSelect.h to CodeSelect.h
    Added IR test code.
2019-10-01 Added shift register chaining diagram.
2019-10-01 Added NodeMCU <-> Arduino pin mapping diagram.
2019-10-15 Added more supporting files
    [28BYJ Window Mount.stl, Assemly_PREVIEW.STL, BatteryBox-4.STL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]
2019-10-15 Replaced missing NodeMCU part.
    When loaded into Fritzing at work, that part was missing. I had to
    download it and import it. That will probably screw up the home version.
    I need to find a portable way to fix this.
    [Control Circuit.fzz]
2019-11-14 Normal open/close via remote control now working.
    Next: get calibration via remote control working.
2019-11-18 IR control now working!
    Note: Due to speed of reads, IR buttons must be toggles.
    Code cleaned up.
2019-12-27 Added pin ID list for switchboard. Fixed misnamed file.
2020-01-01 Started work on a KiCAD schematic.
    [V2.kicad_pcb, V2.sch]
2020-01-01 More work on KiCAD schematic. Believe it to be finished at this point.
    [V2.sch]
2020-01-05 Added V3 KiCAD schematic: V2 with connectors added (not finished).
    Updated switchboard pinout file.
    [V3.kicad_pcb, V3.sch]
2020-01-08 More work on KiCAD schematic.
    Created and added driver board for 28BYJ stepper (board: SBT0811)
    Added more connectors. Next: finish up connectors to driver boards.
    [V3.sch]
2020-01-13 Finished V3 KiCAD schematic.
    Added colors for stepper connections to ensure correct rotation!
    Colors obtained from breadboard pictures.
    [V3.sch]
2020-01-22 Started additional V3 schematic w/ PCB pin location labels.
    TODO: Pull-up resistors need to be installed on the board.
    TODO: The shift register sockets are the wrong size, need to be replaced
    with 16-pin types.
    [V3.with.board.pins.sch]
2020-03-20 Adding working copy of V3 KiCAD files. Began wiring of board. See TODO.
    [V3.kicad_pcb, V3.sch, V3.with.board.pins.sch]
2020-03-25 Diagram updates.
    [V3.sch]
2020-03-27 Abandoned approach of deleting wires in diagram as they are completed. The resultant schematic becomes too hard to follow. Now marking completed connections with a period.
    Added colors to switchboard jack and plug in diagram to minimize
    confusion. Still would be useful to have a diagram of the physical
    connector on the board.
    [V3.sch]
2020-03-27 Added graphic for J7 pins. Added that to schematic.
    [V3.sch]
2020-04-11 Updated diagrams
    [V3.sch]
2020-04-11 Switched over to using Eclipse+PIO.
    Rebuilt and uploaded to device. Tested with one motor, button board, and
    IR remote. Seems to be working fine. On to building an enclosure.
2022-01-10 Added labeled PC board diagram.
2022-01-12 Added more testing code, support for WAVGAT Arduino clone.
